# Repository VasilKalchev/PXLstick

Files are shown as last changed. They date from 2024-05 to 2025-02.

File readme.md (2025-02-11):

# <p align="center">PXL stick v1.1</p>

<p align="center">
  Board for driving WS281x lights with ESP32 running <a href="https://github.com/Aircoookie/WLED">Aircoookie's WLED</a> firmware
</p>

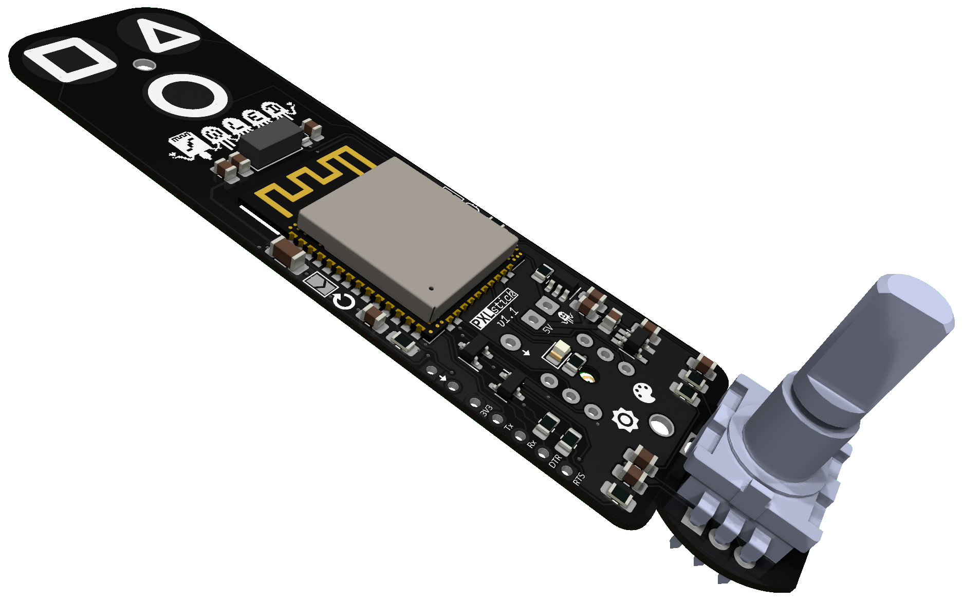
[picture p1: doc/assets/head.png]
images of the 3D render of the board from different angles and of the PCB project



> [Release v1.1](/doc/releaselog.md#v1.1) is a fix for v1.0, but was not fabricated at the time of release.
>
> :memo: Check the latest [release note of this version](https://github.com/VasilKalchev/PXLstick/releases/tag/v1.1) for a possible update on the fabrication status.

### WLED firmware
> [!NOTE]
> If you haven't heard of [WLED][wled_repo], it's best to check it out first.

---

## Characteristics
*The board is intended for mounting on some kind of vertical stick, that has a **WS281x LED strip** on it.*

 - Runs a **custom build** of WLED on a [ESP32-WROOM-32E][esp32_wroom_32e] module.
 - Physically controllable through **2 user configurable touch buttons** and a **rotary encoder** for brightness and color.
 - It also has an **infrared receiver** for further flexibility.
 - Equipped with an I<sup>2</sup>S mic to enable WLED's **audio reactive** effects.
 - **Level shifted** WS281x data signal.
 - **Narrow** form factor: 25x100mm

## How to use it?

1. [PCB fabrication](#1-pcb-fabrication)
2. [Assembly](#2-assembly)
3. [Wiring and mounting](#3-wiring-and-mounting)
4. [Firmware binary](#4-firmware-binary)
5. [Flashing](#5-flashing)
6. [Configuration](#6-configuration)

### 1. PCB fabrication
The [release][repo_release_v1_1] includes [Gerber and drill files][dw_gerbers], generated according to [JLCPCB's instructions][jlcpcb_gerbers_spec]. Other fabricators may have different Gerber and drill files requirements, in which case you'll have to generate the files manually, according to their specification.

If you have made modifications to the PCB and want to regenerate the exports - you can use the scripts provided in [/hw/export/](/hw/export/).

### 2. Assembly
#### INMP441 mic
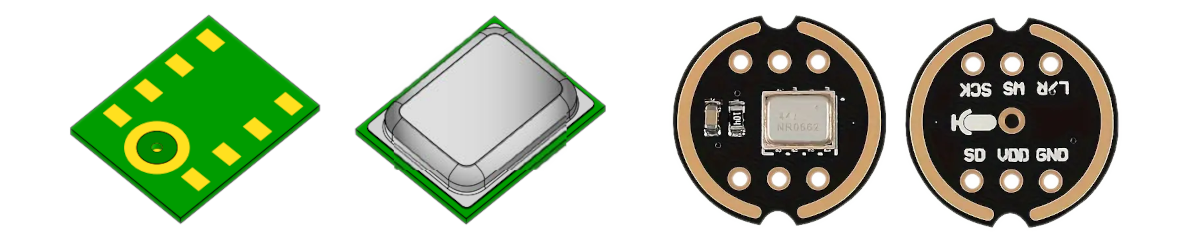
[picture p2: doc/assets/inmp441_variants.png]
INMP441 variants


There are two footprints for the INMP441 mic. *U3* is for its 9-terminal LGA_CAV package (located on the back of the PCB) and *A1* is for its breakout board (can be soldered on either side). When using the breakout board - don't solder *C7*, *R9* and *R10*.

#### Optional peripherals
 - IR receiver (*U2, R8, C6*)
 - rotary encoder (*RE1, R2, R3, R4, C3, C4, C5*)
 - microphone (*U2/A1, R9, R10, C7*)
 - power status LED (*D1, R1*)

### 3. Wiring and mounting
The board is powered with 5V by soldering wires to the through-hole pads marked with "5V" and the symbol for ground (located below ESP32-WROOM-32E).

WS281x's data wire is soldered to the through-hole pad marked with the LED graphic.

Recommended rotary encoder's knob diameter is 20mm.

Holes *H1* and *H2* are used for mounting the board with 2mm screws.

### 4. Firmware binary
The [release][repo_release_v1_1] includes a [custom WLED build][dw_binary] compiled with a rotary encoder "usermod" and preconfigured. If you're not planning on using the rotary encoder, you can use the official build.

If you want to customize your build further - you can use my [fork of WLED][wled_fork] which includes the [configuration][wled_fork_cfg] for the custom build.

### 5. Flashing
Flashing the firmware for the first time requires connecting to the board through a USB to serial adapter.

The programming pins are exposed on the left side of the board. You can avoid soldering a pin header and just put a header or jumper wires through the plated holes.

> [!TIP]
> If you get an error while flashing firmware - try putting ESP32 in bootloader mode manually.
>
> This is done by momentarily pulling pin "EN" low (restart) while pin "BOOT" is pulled low. Pins "EN" and "BOOT" are exposed as pads, "EN" is located to the left of the ESP32 module and "BOOT" is to the right. Shorting these pads - pulls the pins low.

#### Method A: Flashing directly with Espressif's `esptool`
1. Follow the [instructions to install esptool][esptool_install].
2. Flash [WLED's bootloader][dw_bootloader]:
```
esptool.py write_flash 0x0 ./esp32_bootloader_v4.bin
```
3. Flash the firmware binary:
```
esptool.py write_flash 0x10000 ./WLED_XXX.bin
```

If you experience issues - try erasing the flash first:
```
esptool.py erase_flash
```

> [!NOTE]
> This method is taken from [WLED's documentation][wled_flash_method2] web site.

#### Method B: Flashing with WLED's web installer and performing an OTA update
You can avoid installing `esptool` by using [WLED's web installer][wled_web_installer] to flash WLED's official firmware and then performing an OTA update with the provided custom binary.

### 6. Configuration
You can now continue with [WLED's getting started guide][wled_getting_started_guide] to configure your board.

> [!TIP]
> After connecting the board to your Wi-Fi network you can apply the provided base configuration by going to "Config" > "Security & Updates" > "Restore configuration" and uploading the provided [base configuration file][dw_base_cfg] (after that, you'll have to configure the Wi-Fi again).

#### Board connections:
| Function | GPIO |
|---|---|
| WS281x | GPIO 4  |
| "square" | GPIO 32 |
| "triangle"  | GPIO 33 |
| "circle" | GPIO 14 |
| RE 1 | GPIO 27 |
| RE 2 | GPIO 16 |
| RE BTN | GPIO 17 |
| LED | GPIO 2  |
| IR receiver | GPIO 23 |
| INMP441 SD  | GPIO 15 |
| INMP441 WS  | GPIO 13 |
| INMP441 SCK | GPIO 25 |

<!-- links -->
[head_img]: /doc/assets/head.png
[inmp441_variants_img]: /doc/assets/inmp441_variants.png

[releaselog_v1_1]: /doc/releaselog.md#v11---2025-02-11 "/doc/releaselog.md"
[repo_release_v1_1]: https://github.com/VasilKalchev/PXLstick/releases/tag/v1.1 "PXL stick version v1.1"
[repo_releases]: https://github.com/VasilKalchev/PXLstick/releases "All PXL stick releases"

[wled_repo]: https://github.com/Aircoookie/WLED "WLED's repository"
[esp32_wroom_32e]: https://www.espressif.com/sites/default/files/documentation/esp32-wroom-32e_esp32-wroom-32ue_datasheet_en.pdf "ESP32-WROOM-32E datasheet"
[inmp441]: https://invensense.tdk.com/wp-content/uploads/2015/02/INMP441.pdf "INMP441 datasheet"
[jlcpcb_gerbers_spec]: https://jlcpcb.com/help/article/362-how-to-generate-gerber-and-drill-files-in-kicad-7 "JLCPCB: How to generate Gerber and drill files in KiCad 7"

[dw_gerbers]: https://github.com/VasilKalchev/PXLstick/releases/download/v1.1/gerbers_jlcpcb.zip "Download gerbers_jlcpcb.zip"
[dw_binary]: https://github.com/VasilKalchev/PXLstick/releases/download/v1.1/WLED_0.14.3_PXLstick_v1.1.bin "Download WLED_0.14.3_PXLstick_v1.1.bin"
[dw_bootloader]: https://github.com/Aircoookie/WLED/releases/download/v0.13.1/esp32_bootloader_v4.bin "Download esp32_bootloader_v4.bin"
[dw_base_cfg]: https://github.com/VasilKalchev/PXLstick/releases/download/v1.1/WLED_0.14.3_PXLstick_v1.1_basecfg.json "Download WLED_0.14.3_PXLstick_v1.1_basecfg.json"

[wled_fork]: https://github.com/VasilKalchev/WLED "Fork of WLED repository for custom builds"
[wled_fork_cfg]: https://github.com/VasilKalchev/WLED/blob/4febf0a671bf4d266bcb785312891e56a2469468/platformio.ini#L836-L875 "Custom build configuration for PXL stick v1"

[esptool_install]: https://docs.espressif.com/projects/esptool/en/latest/esp32/ "Espressif's esptool.py documentation"
[wled_web_installer]: https://install.wled.me/

[wled_flash_method2]: https://kno.wled.ge/basics/install-binary/#:~:text=properly%20by%20WLED.-,Flashing%20method%202%3A%20esptool,-First%20of%20all "WLED's flashing guide: method 2"
[wled_getting_started_guide]: https://kno.wled.ge/basics/getting-started/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 "WLED's getting started guide: Wi-Fi configuration"

<!-- checklist & fabrication result template

<details>
<summary>/readme.md checklist</summary>

 - [x] set current version (after project name)
 - [x] set fabrication status
 - [x] update sections: [Characteristics](#characteristics) and [How to use it?](#how-to-use-it)
 - [x] comment out this "checklist" and "templates" sections

</details>

<details>
<summary>/readme.md templates</summary>

## "Fabrication result" section:

![bad fabrication](https://img.shields.io/badge/bad-firebrick?style=for-the-badge&label=fabrication%20result)
> The fabricated board from release vX.Y [didn't work](/doc/releaselog.md#vXY---202Y-MM-DD).
>
> :exclamation: Browse [repository releases][repo_releases] for a better version.

---

![poor fabrication](https://img.shields.io/badge/poor-orangered?style=for-the-badge&label=fabrication%20result)
> The fabricated board from release vX.Y worked, but has [significant problems](/doc/releaselog.md#vXY---202Y-MM-DD).
>
> :exclamation: Browse [repository releases][repo_releases] for a better version.

---

![average fabrication](https://img.shields.io/badge/average-yellow?style=for-the-badge&label=fabrication%20result)
> The fabricated board from release vX.Y worked, but has [some problems](/doc/releaselog.md#vXY---202Y-MM-DD).
>
> :grey_exclamation: Browse [repository releases][repo_releases] for a better version.

---

![ok fabrication](https://img.shields.io/badge/ok-greenyellow?style=for-the-badge&label=fabrication%20result)
> The fabricated board from release vX.Y worked, but has [minor problems](/doc/releaselog.md#vXY---202Y-MM-DD).
>
> :memo: Browse [repository releases][repo_releases] for a better version.

---

![good fabrication](https://img.shields.io/badge/good-limegreen?style=for-the-badge&label=fabrication%20result)
> The fabricated board from release vX.Y worked without problems!
>
> :tada: Recommended for fabrication.

---

![in development](https://img.shields.io/badge/in_development-dimgrey?style=for-the-badge&label=fabrication%20result)
> This version is currently in development...
>
> :hourglass_flowing_sand: Wait for the release or browse [repository releases][repo_releases] for an older, completed version.

---

![will not fabricate](https://img.shields.io/badge/won\'t_be_fabricated-firebrick?style=for-the-badge&label=fabrication%20result)
> Release vX.Y won't be fabricated, because ... .
>
> :exclamation: Browse [repository releases][repo_releases] for a better version.

---

![fix, not fabricated](https://img.shields.io/badge/fix%20(not%20fabricated)-indigo?style=for-the-badge&label=fabrication%20result)
> [Release vX.Y](/doc/releaselog.md#vX.Y) is a fix for vX.Y, but was not fabricated at the time of release.
>
> :memo: Check the latest [release note of this version](https://github.com/VasilKalchev/PXLstick/releases/tag/vX.Y) for a possible update on the fabrication status.

</details>

-->

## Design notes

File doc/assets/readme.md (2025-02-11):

Images used in repository's readmes.

<!--

<details>
<summary>assets checklist</summary>

 - [x] export images of the 3D render of the board
 - [x] make a head image for use in [/readme.md](/readme.md)

 - [x] comment out this section

</details>

-->

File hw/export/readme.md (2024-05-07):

Gerbers, BOM, schematic and PCB sheets exports.

> [!TIP]
> Use the scripts to generate exports.

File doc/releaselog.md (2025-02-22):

# Release log
Fabrication results.

## v1.1 - 2025-02-11

> [Release v1.1](/doc/releaselog.md#v1.1) is a fix for v1.0, but was not fabricated at the time of release.
>
> :memo: Check the latest [release note of this version](https://github.com/VasilKalchev/PXLstick/releases/tag/v1.1) for a possible update on the fabrication status.

### Properties:
 - Fabricator: JLCPCB
 - Material: FR4 (Tg 135)
 - Layers: 2
 - PCB thickness: 1.6mm
 - Solder mask color: black
 - Silkscreen: white
 - Surface finish: HASL (with lead)
 - Copper weight: 1 oz
 - Via covering: tented
 - Board outline tolerance: +-0.2mm
 - Appearance quality: IPC Class 2 Standard
 - Silkscreen technology: Ink-jet/screen printing

## v1.0-obsolete - 2023-06-11

> Works, but has significant problems.

### Properties:
 - Fabricator: JLCPCB
 - Material: FR4 (Tg 135)
 - Layers: 2
 - PCB thickness: 1.2mm
 - Solder mask color: black
 - Silkscreen: white
 - Surface finish: HASL (with lead)
 - Copper weight: 1 oz
 - Via covering: tented
 - Board outline tolerance: +-0.2mm
 - Appearance quality: IPC Class 2 Standard
 - Silkscreen technology: Ink-jet/screen printing

### Problems:
#### Major
 - touch button on GPIO0/BOOT doesn't work properly, leaving the circle shape unused
 - no pull-up resistor on ESP32 pin EN
 - rotary encoder function icons don't match the actual modes

#### Minor
 - wire holes diameter is too narrow
 - touch buttons work better without resistors
 - WS281x signal overshoots and rings on long wire with the specified resistor value range
 - the power LED is too bright with the specified 330 ohm resistor
 - circle shape appears a bit larger than the others
 - release version is not visually accessible on the bottom layer once mounted

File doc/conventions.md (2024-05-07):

# Conventions

## Versioning
### Hardware (board)
Board releases are made with a major and a minor version (e.g. "PXL stick v1.2").

The major version is incremented when making incompatible changes to the board (including simple pin rearrangements). The minor version is incremented for simple fixes or small additions.

### Firmware (WLED)
The binary version is the combination of WLED's version and the board's version (e.g. `WLED_0.14.3_PXLstick_5.8.bin`).

Different board major versions require different firmware builds (e.g. "PXL stick v1.9" and "PXL stick v2.1" require different builds). A binary version with higher board minor version is backwards compatible with older boards of the same major version (e.g. `WLED_0.14.3_PXLstick_1.9.bin` is compatible with boards "PXL stick v1.9", "PXL stick v1.8" and so on).

After WLED release, the binaries should be rebuild with the new WLED version (e.g. `WLED_0.14.3_PXLstick_5.8.bin` becomes `WLED_0.15.0_PXLstick_5.8.bin`)

## Development and release
### Before starting development
New board versions are developed in a separate branch.

### During development
Every change to the board is documented in [changelog.md](changelog.md).

### Before release
The [release_checklist.md](release_checklist.md) is completed.

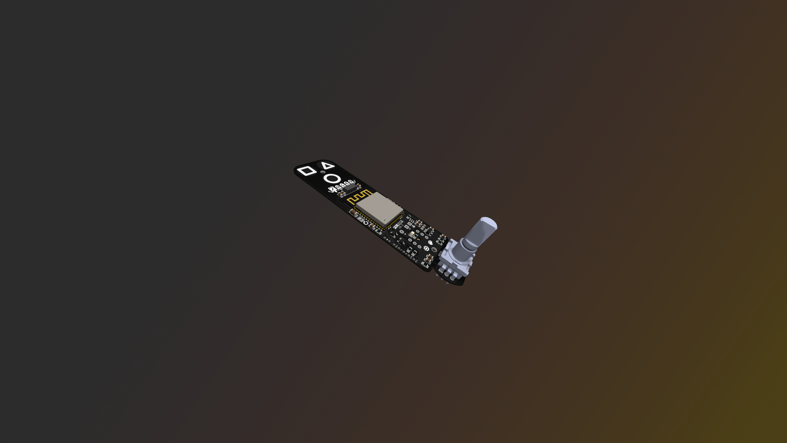
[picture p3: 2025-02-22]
img/wall-pxlstick1.1-diag-smaller.png

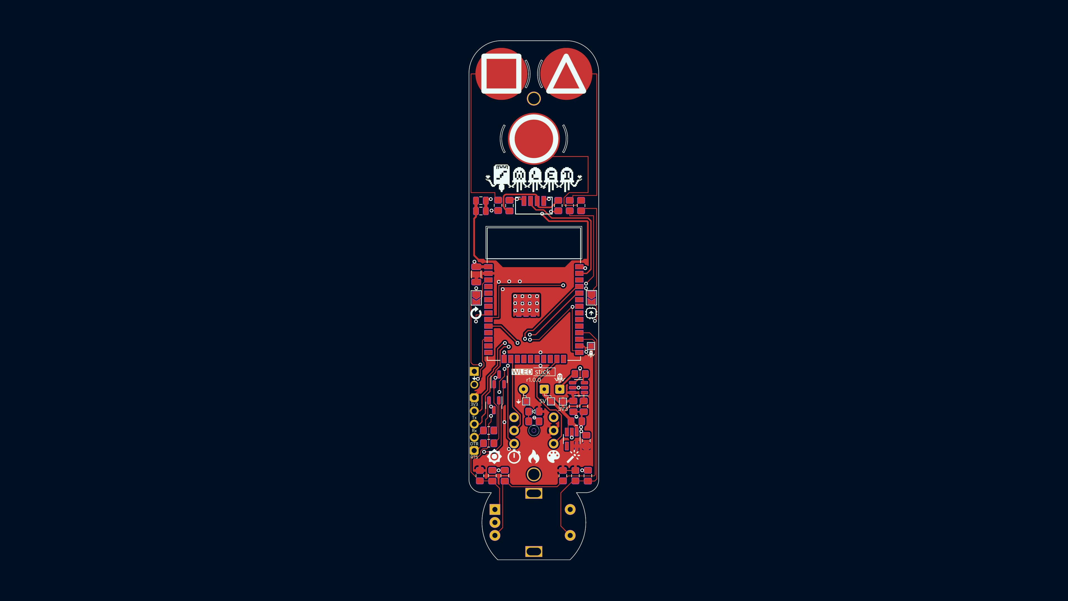
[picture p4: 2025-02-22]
img/wall-pxlstick1.0-pcb-front.png

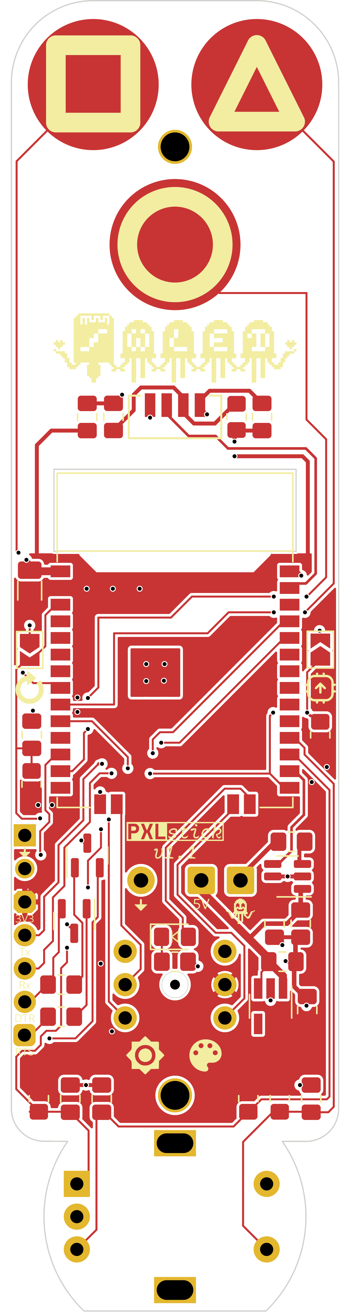
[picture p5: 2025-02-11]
img/pcb-front.png

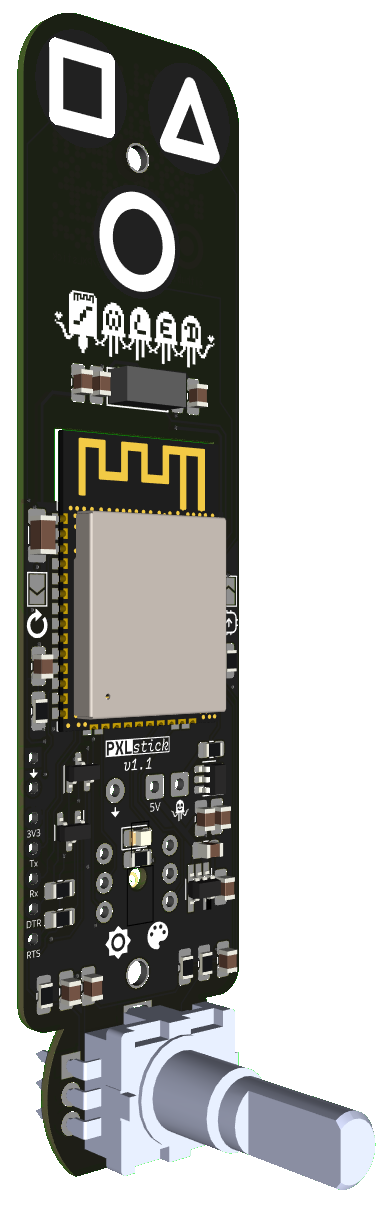
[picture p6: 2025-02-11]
img/3d-side.png

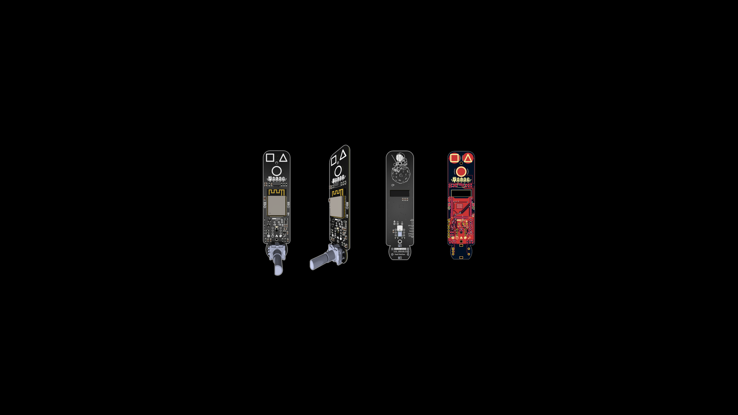
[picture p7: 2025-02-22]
img/wall-pxlstick1.0-all.png

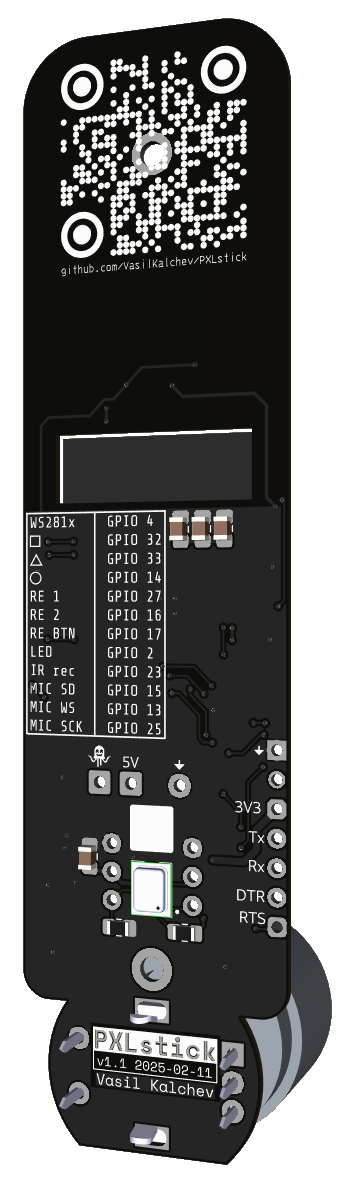
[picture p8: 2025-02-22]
img/3d-back.png

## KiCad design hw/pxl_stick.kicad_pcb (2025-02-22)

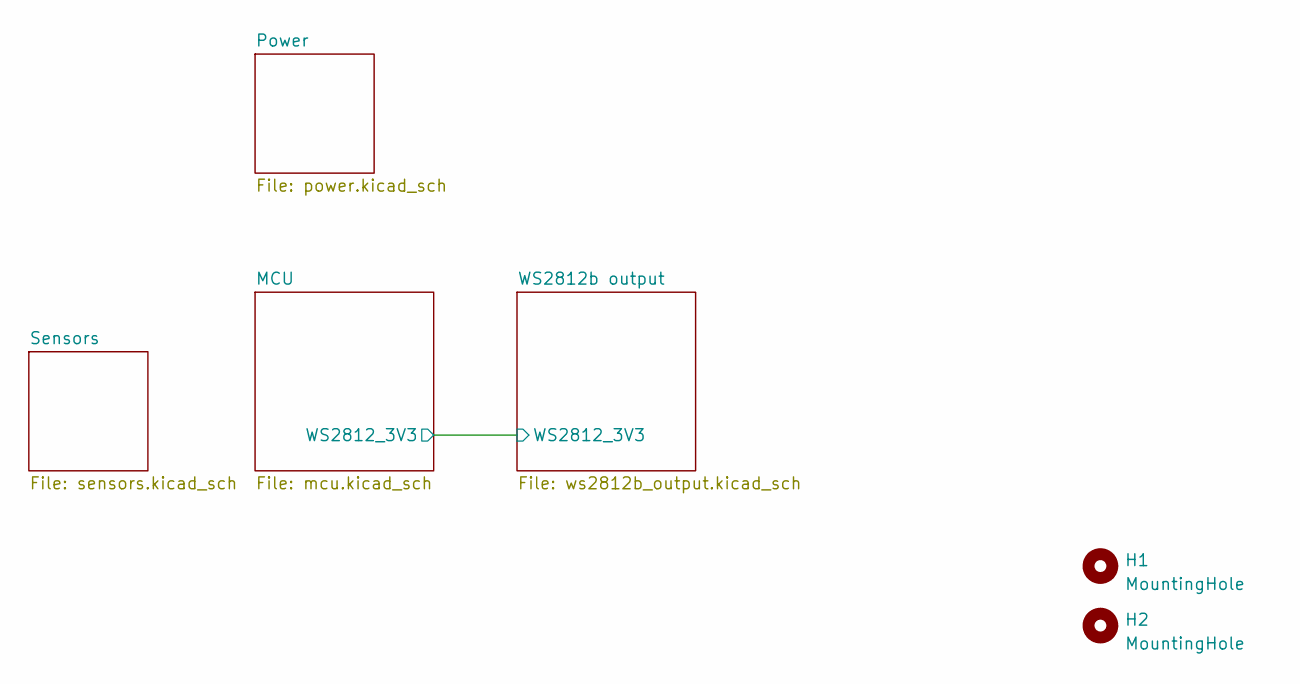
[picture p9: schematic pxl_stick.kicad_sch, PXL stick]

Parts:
H1, H2: MountingHole; MountingHole_2.2mm_M2_ISO14580_Pad_TopOnly

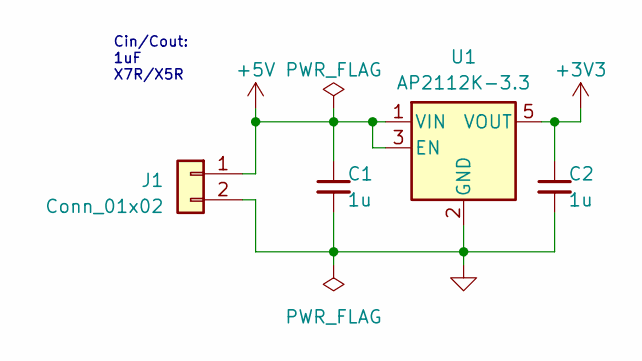
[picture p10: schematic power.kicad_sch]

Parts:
C1, C2: 1u; C_0805_2012Metric_Pad1.18x1.45mm_HandSolder
J1: Conn_01x02; SolderWire-0.5sqmm_1x02_P4.6mm_D0.9mm_OD2.1mm
U1: AP2112K-3.3; SOT-23-5_HandSoldering

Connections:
+3V3: C2.1, U1.5 (VOUT); also elsewhere on the board
+5V: C1.1, J1.1, U1.1 (VIN), U1.3 (EN); also elsewhere on the board
GND: C1.2, C2.2, J1.2, U1.2 (GND); also elsewhere on the board

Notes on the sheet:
Cin/Cout: 1uF X7R/X5R

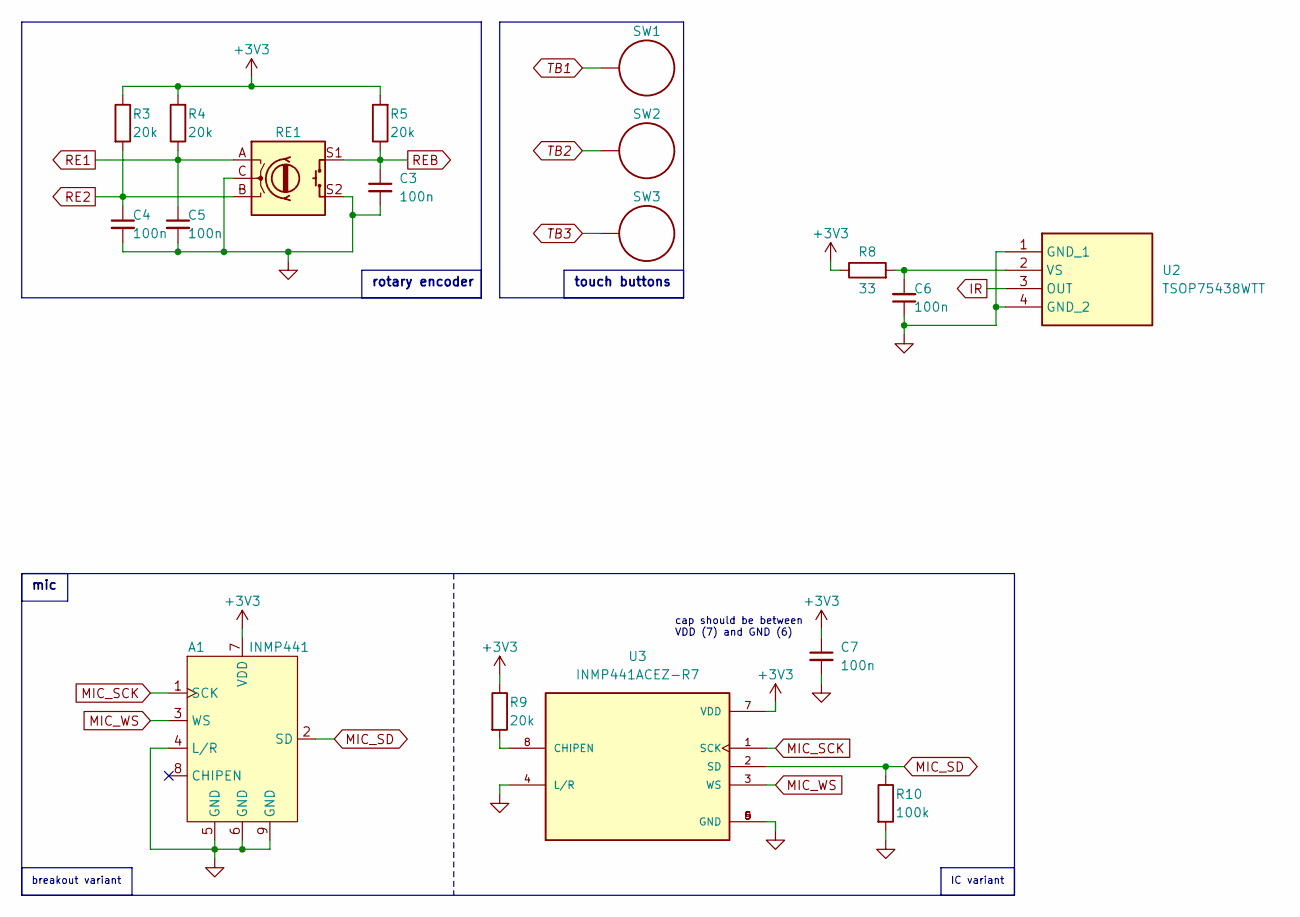
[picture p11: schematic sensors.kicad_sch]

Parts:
A1: INMP441; INMP441 breakout
C3, C4, C5, C6, C7: 100n; C_0805_2012Metric_Pad1.18x1.45mm_HandSolder
R3, R4, R5, R9: 20k; R_0805_2012Metric_Pad1.20x1.40mm_HandSolder
R8: 33; R_0805_2012Metric_Pad1.20x1.40mm_HandSolder
R10: 100k; R_0805_2012Metric_Pad1.20x1.40mm_HandSolder
RE1: RotaryEncoder_Switch; RotaryEncoder_Alps_EC11E-Switch_Vertical_H20mm
SW1, SW2, SW3: Touch_Circular_10mm
U2: TSOP75438WTT; TSOP75_WTT_VIS; Mouser Part Number 78-TSOP75438WTT
U3: INMP441ACEZ-R7; PARTREV 1.1

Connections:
+3V3: A1.7 (VDD), C7.1, R3.1, R4.2, R5.2, R8.1, R9.1, U3.7 (VDD); also elsewhere on the board
GND: A1.4 (L/R), A1.5 (GND), A1.6 (GND), A1.9 (GND), C3.2, C4.2, C5.2, C6.1, C7.2, R10.2, RE1.C, RE1.S2, U2.1 (GND_1), U2.4 (GND_2), U3.4 (L/R), U3.5 (GND), U3.6 (GND), U3.9 (GND); also elsewhere on the board
IR: U2.3 (OUT); also elsewhere on the board
MIC_SCK: A1.1 (SCK), U3.1 (SCK); also elsewhere on the board
MIC_SD: A1.2 (SD), R10.1, U3.2 (SD); also elsewhere on the board
MIC_WS: A1.3 (WS), U3.3 (WS); also elsewhere on the board
unnamed: C6.2, R8.2, U2.2 (VS)
unnamed: R9.2, U3.8 (CHIPEN)
RE1: C5.1, R4.1, RE1.A; also elsewhere on the board
RE2: C4.1, R3.2, RE1.B; also elsewhere on the board
REB: C3.1, R5.1, RE1.S1; also elsewhere on the board
TB1: SW1.1; also elsewhere on the board
TB2: SW2.1; also elsewhere on the board
TB3: SW3.1; also elsewhere on the board

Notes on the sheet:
rotary encoder
touch buttons
cap should be between VDD (7) and GND (6)
mic
breakout variant
IC variant

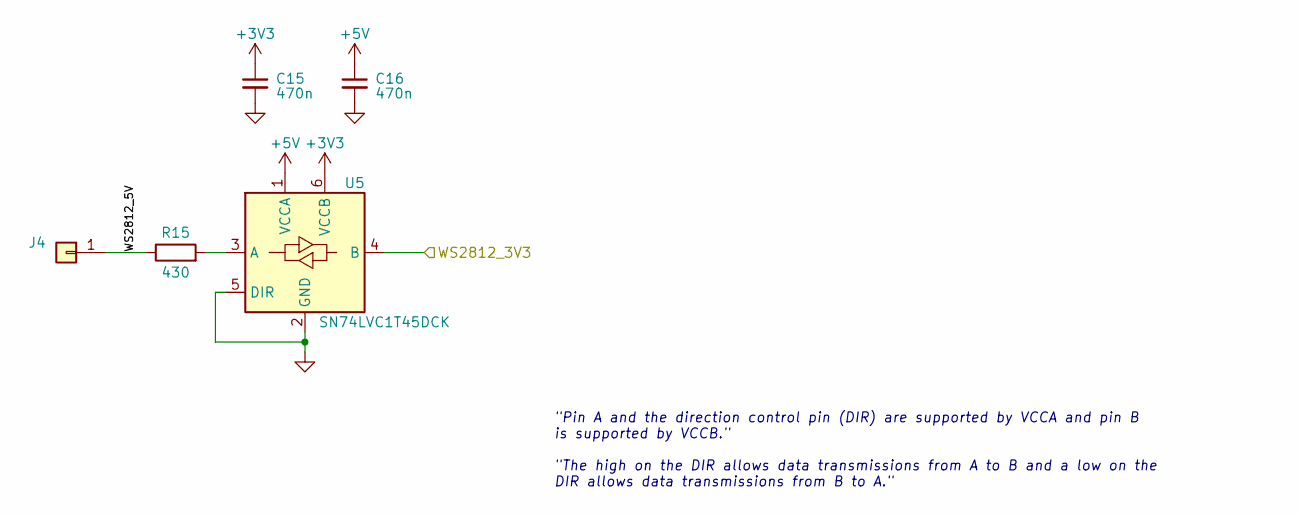
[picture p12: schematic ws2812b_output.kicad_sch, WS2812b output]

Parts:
C15, C16: 470n; C_0805_2012Metric_Pad1.18x1.45mm_HandSolder
J4: Conn_01x01; SolderWire-0.5sqmm_1x01_D0.9mm_OD2.1mm
R15: 430; R_0805_2012Metric_Pad1.20x1.40mm_HandSolder
U5: SN74LVC1T45DCK; SOT-23-6

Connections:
+3V3: C15.1, U5.6 (VCCB); also elsewhere on the board
+5V: C16.1, U5.1 (VCCA); also elsewhere on the board
/MCU/WS2812_3V3: U5.4 (B); also elsewhere on the board
/WS2812b output/WS2812_5V: J4.1, R15.1
GND: C15.2, C16.2, U5.2 (GND), U5.5 (DIR); also elsewhere on the board
unnamed: R15.2, U5.3 (A)

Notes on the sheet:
"Pin A and the direction control pin (DIR) are supported by VCCA and pin B is supported by VCCB." "The high on the DIR allows data transmissions from A to B and a low on the DIR allows data transmissions from B to A."

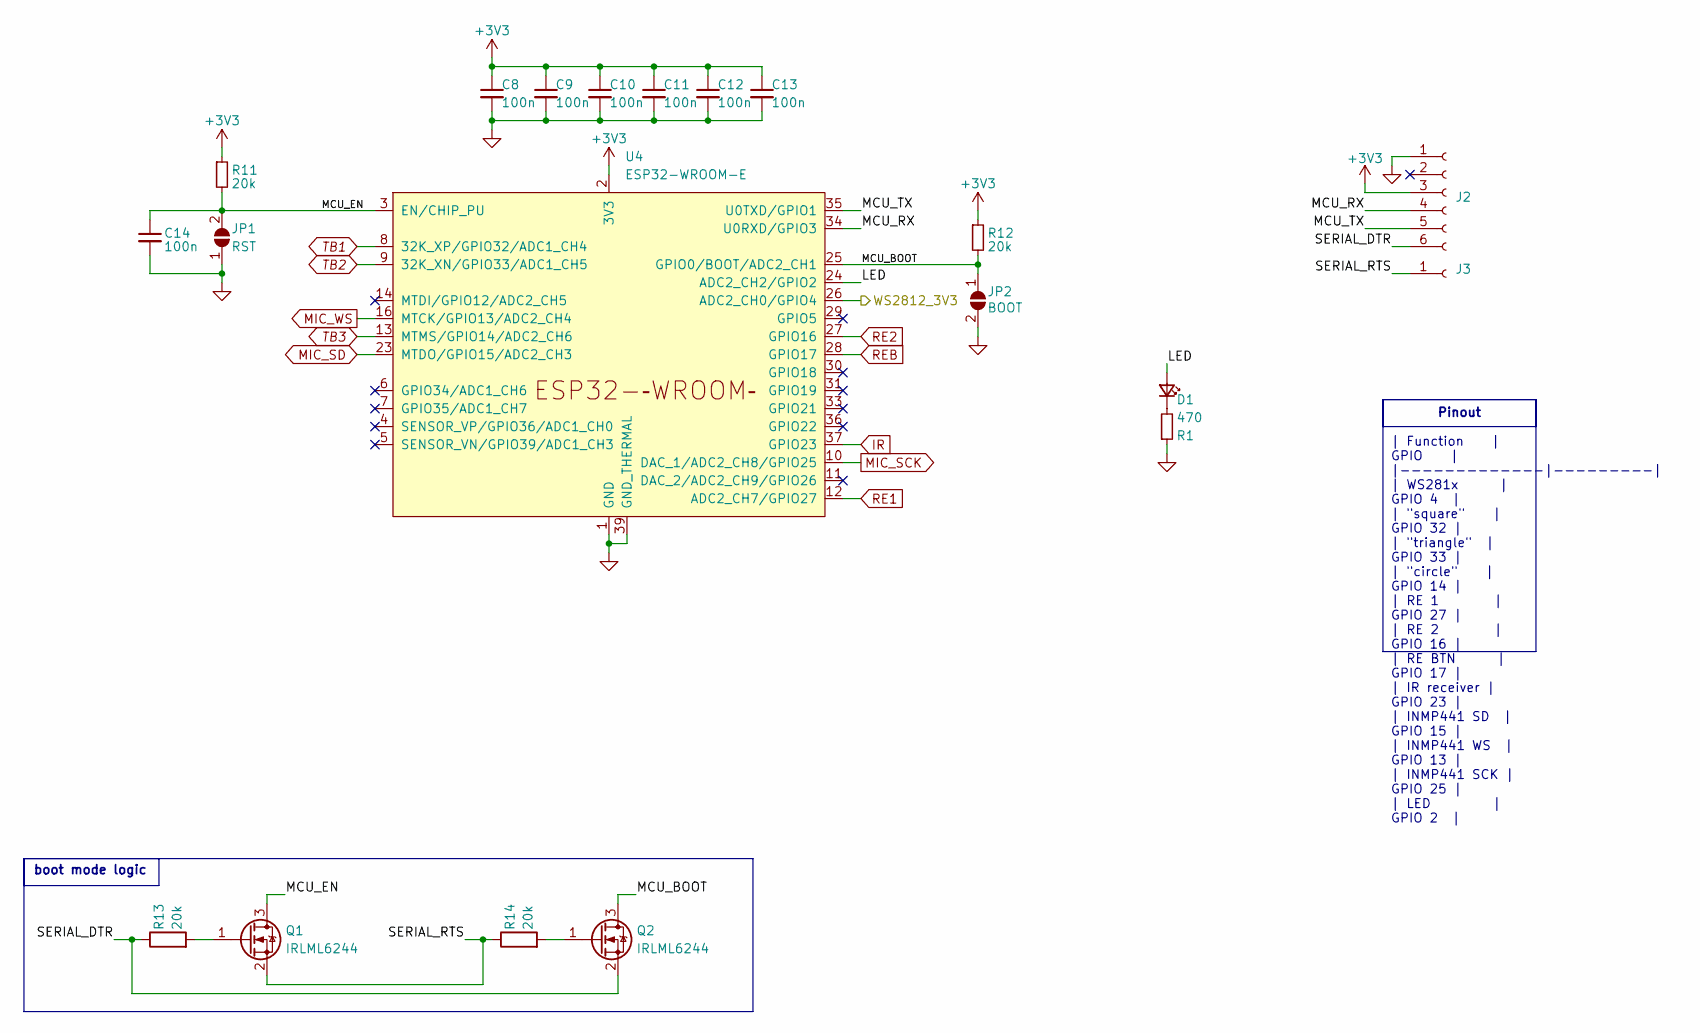
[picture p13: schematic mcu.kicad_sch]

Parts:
C8: 100n; C_1206_3216Metric_Pad1.33x1.80mm_HandSolder
C9, C10, C11, C12, C13, C14: 100n; C_0805_2012Metric_Pad1.18x1.45mm_HandSolder
D1: LED_Small; LED_0805_2012Metric_Pad1.15x1.40mm_HandSolder
J2: Conn_01x06_Socket; PinSocket_1x06_P2.54mm_Vertical
J3: Conn_01x01_Socket; PinSocket_1x01_P2.54mm_Vertical
JP1: RST; SolderJumper-2_P1.3mm_Open_TrianglePad1.0x1.5mm
JP2: BOOT; SolderJumper-2_P1.3mm_Open_TrianglePad1.0x1.5mm
Q1, Q2: IRLML6244; SOT-23
R1: 470; R_0805_2012Metric_Pad1.20x1.40mm_HandSolder
R11, R12, R13, R14: 20k; R_0805_2012Metric_Pad1.20x1.40mm_HandSolder
U4: ESP32-WROOM-E; ESP32-WROOM-32E

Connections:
+3V3: C8.1, C9.1, C10.1, C11.1, C12.1, C13.1, J2.3, R11.1, R12.1, U4.2 (3V3); also elsewhere on the board
/MCU/LED: D1.2 (A), U4.24 (ADC2_CH2/GPIO2)
/MCU/MCU_BOOT: JP2.1 (A), Q2.3 (D), R12.2, U4.25 (GPIO0/BOOT/ADC2_CH1)
/MCU/MCU_EN: C14.1, JP1.2 (B), Q1.3 (D), R11.2, U4.3 (EN/CHIP_PU)
/MCU/MCU_RX: J2.4, U4.34 (U0RXD/GPIO3)
/MCU/MCU_TX: J2.5, U4.35 (U0TXD/GPIO1)
/MCU/SERIAL_DTR: J2.6, Q2.2 (S), R13.1
/MCU/SERIAL_RTS: J3.1, Q1.2 (S), R14.1
/MCU/WS2812_3V3: U4.26 (ADC2_CH0/GPIO4); also elsewhere on the board
GND: C8.2, C9.2, C10.2, C11.2, C12.2, C13.2, C14.2, J2.1, JP1.1 (A), JP2.2 (B), R1.1, U4.1 (GND), U4.15 (GND), U4.38 (GND), U4.39 (GND_THERMAL); also elsewhere on the board
IR: U4.37 (GPIO23); also elsewhere on the board
MIC_SCK: U4.10 (DAC_1/ADC2_CH8/GPIO25); also elsewhere on the board
MIC_SD: U4.23 (MTDO/GPIO15/ADC2_CH3); also elsewhere on the board
MIC_WS: U4.16 (MTCK/GPIO13/ADC2_CH4); also elsewhere on the board
unnamed: D1.1 (K), R1.2
unnamed: Q1.1 (G), R13.2
unnamed: Q2.1 (G), R14.2
RE1: U4.12 (ADC2_CH7/GPIO27); also elsewhere on the board
RE2: U4.27 (GPIO16); also elsewhere on the board
REB: U4.28 (GPIO17); also elsewhere on the board
TB1: U4.8 (32K_XP/GPIO32/ADC1_CH4); also elsewhere on the board
TB2: U4.9 (32K_XN/GPIO33/ADC1_CH5); also elsewhere on the board
TB3: U4.13 (MTMS/GPIO14/ADC2_CH6); also elsewhere on the board

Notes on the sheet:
| Function | GPIO | |-------------|---------| | WS281x | GPIO 4 | | "square" | GPIO 32 | | "triangle" | GPIO 33 | | "circle" | GPIO 14 | | RE 1 | GPIO 27 | | RE 2 | GPIO 16 | | RE BTN | GPIO 17 | | IR receiver | GPIO 23 | | INMP441 SD | GPIO 15 | | INMP441 WS | GPIO 13 | | INMP441 SCK | GPIO 25 | |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
Pinout
boot mode logic

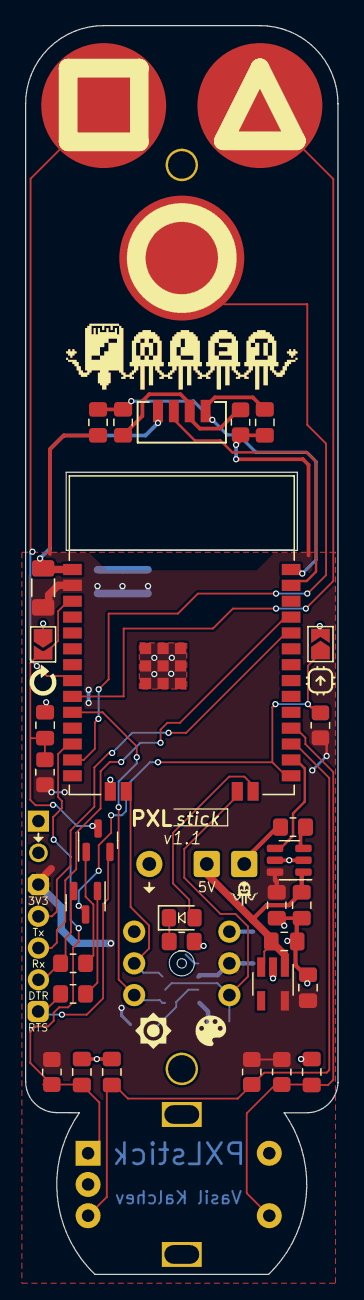
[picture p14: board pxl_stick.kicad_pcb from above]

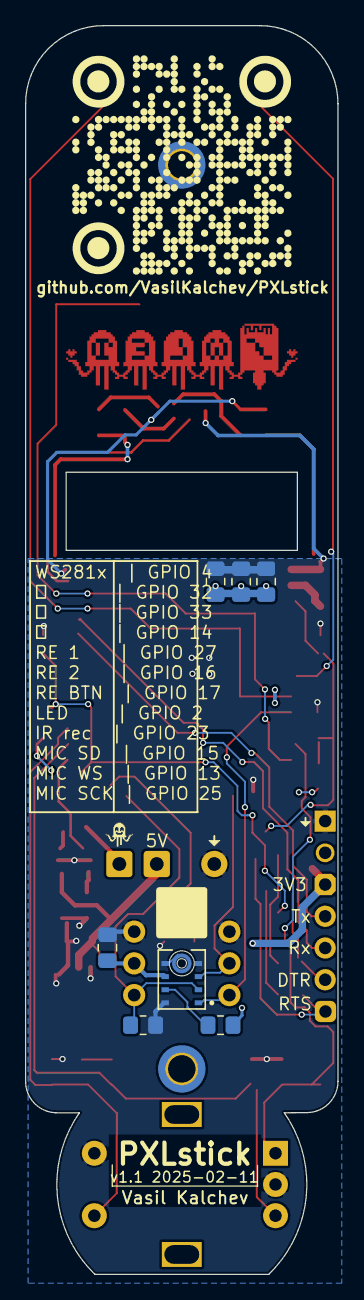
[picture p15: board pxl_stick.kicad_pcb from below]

Board: 2 copper layers, 25.0 x 99.9 mm, 56 parts (12 on the bottom side), 28 nets.

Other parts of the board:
ss1: qr; LOGO
ss2: wled logo; LOGO
ss3: ws281x signal; LOGO
ss4: brightness; LOGO
ss5: palette; LOGO
ss6: reset; LOGO
ss7: bootloader; LOGO

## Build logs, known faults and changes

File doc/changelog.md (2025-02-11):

# Change log

## v1.1 - 2025-02-11
### Schematic
#### Added
 - Pull-up resistors to "EN" and "BOOT" pins.
 - Capacitor to "EN" pin.

#### Fixed
 - Moved touch button "circle" from GPIO0 to GPIO14.

#### Changed
 - Moved LED from power rail to GPIO2.
 - Increased LED's resistor from 330Ω to 470Ω.
 - Increased all pull-up resistors from 10kΩ to 20kΩ.
 - Increased SN74LVC1T45DCK's output resistor from 33Ω to 430Ω.
 - Increased SN74LVC1T45DCK's capacitors to 470n.

#### Removed
 - RST and BOOT buttons (were DNP).
 - Series resistors from touch buttons.
 - All test points.

### Board
#### Changed
 - Decreased copper pour clearance to 0.2mm.
 - Decreased traces width from 0.3mm to 0.2mm.
 - Increased wire holes diameters from 0.4mm to 0.9mm.
 - Silkscreen board name to "PXLstick".
 - Increased widths of touch buttons' silkscreen shapes.

#### Removed
 - Unused rotary encoder's silkscreen icons.
 - Some unused ESP32 pads.

## v1.0 - 2023-06-11
First release.

<!-- template

## vX.Y-type - 202Y-MM-DD
Comment...

## Schematic/Board
### Added
 - ... (#<issue>)
 -

### Fixed
 -
 -

### Changed
 -
 -

### Removed
 -
 -

-->

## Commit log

2024-05-08 Enable detection of KiCad files by linguist (#1)
2025-02-11 Version 1.1 changes
    [mcu.kicad_sch, power.kicad_sch, pxl_stick.kicad_pcb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]
2025-02-11 Ignore exported 3d models and KiCad temporary files
2025-02-11 Export and process new images of the board
2025-02-11 Change to single board
2025-02-12 Fix via annular width, remove netties
    [mcu.kicad_sch, pxl_stick.kicad_pcb]
2025-02-20 change smalles hole to 0.3mm
    [pxl_stick.kicad_pcb]
2025-02-22 Add 3D models for rotary encoder knobs
2025-02-22 Change FR-4 color to black for better 3D image export
    [pxl_stick.kicad_pcb]
2026-11-06 Fix docs, export scripts and U5 part value
    - readme: microphone parts are U3/A1 (U2 is the IR receiver), fix
    releaselog anchors, note that the v1.1 firmware enables only 2 of
    the 3 touch buttons, point WLED links to wled/WLED
    - conventions: replace dead release_checklist.md link with a
    description of its lifecycle and a link to the last copy
    - export scripts: add shebang and `set -eu`, run relative to the
    script's directory, use `mkdir -p`; quote ${QUANTITY} in the BOM
    export so the quantity column is no longer dropped by the shell
    - U5: value SN74LVC1T45DCK -> SN74LVC1T45DBV to match its SOT-23-6
    footprint, recorded as a v1.1 erratum in the changelog
